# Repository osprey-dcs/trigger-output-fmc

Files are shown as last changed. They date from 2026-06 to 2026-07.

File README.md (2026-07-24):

# Trigger Output FMC

A single width HPC FMC board which provides 16 low jitter TTL outputs,
along with two Si5394 jitter cleaners with outputs connected to the MGTREF capable
when matched with the [LBL Marble](https://github.com/BerkeleyLab/Marble) FMC carrier.

This design is Open Hardware created by Osprey DCS and published under the terms of the
[CERN Open Hardware Licence Version 2 - Strongly Reciprocal](cern_ohl_s_v2.txt) license.

This repository contains KiCad 9.0.4 design files.

- [Data sheet](datasheet.md)
- [Current generated](https://osprey-dcs.github.io/trigger-output-fmc/)
  - [Schematic](https://osprey-dcs.github.io/trigger-output-fmc/trigger-output-fmc-schematic.pdf)
  - [BoM](https://osprey-dcs.github.io/trigger-output-fmc/trigger-output-fmc-bom.csv)
  - [STeP model](https://osprey-dcs.github.io/trigger-output-fmc/3D/trigger-output-fmc-3D.step)

## Block Diagram

Block diagra

## Status

Incomplete, under development, and not yet produced.

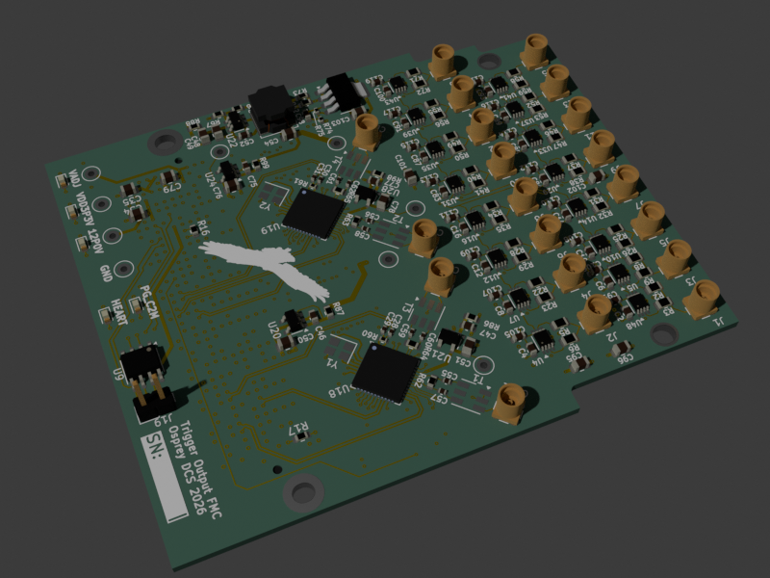
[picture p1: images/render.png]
Preview Render


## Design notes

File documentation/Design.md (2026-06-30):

# Osprey EVR FMC Design Goals

## High level specifications
### Jitter Cleaner
- 2+ LVDS outputs
- Controlled by 2.5V logic from the FPGA (to avoid level shifting)
- Frequencies of interest are 100MHz-250MHz

### Digital I/O
- 16+ outputs with a couple of inputs
- Some/all outputs can drive 50ohm
- Better than 20ps of jitter on clocked digital outputs

# Osprey EVR FMC Part Selection

## Clock Jitter Cleaner Selection

### Skyworks Parts
#### Si5315/16/17/19 - 300pS jitter
- These parts are quite simple and similar
- 3rd Gen DSPLL
- They have a PPL Bypass mode which could be nice for testing.
- CON - these parts seem optimized to operate at fixed tables of frequencies, but will work at 125MHz
Out of this bunch the Si5317A/B seems like it best matches our needs. has 125MHz +/-5MHz options.
These are available form Mouser and Digikey for $15-$20

#### Si5342-45 - 90pS jitter
- 4th Gen DSPLL
- Recommended DSPLLs for Line Card by Skyworks: [link](https://www.skyworksinc.com/-/media/Skyworks/SL/documents/public/application-notes/an1077-selecting-clocks-for-timing-synchronization.pdf)
 - Con - may need level shifting for SPI bus
Out of this bunch the Si5342B seems like it best matches our needs.
These are available form Mouser and Digikey for $26
#### Si5392-95 - 75pS jitter
- This part was used by Paul B. in another similar role but is a clock gen
- 4th Gen DSPLL
- A slightly updated Si534* part with similar combabilities (Drop-in compatible) but options for integrated XTAL
Either Si5392 or Si5394 with a A or B speed grade
These are available form Mouser and Digikey for $35-40
### TI Parts
#### LMK04100 family ~ 200pS jitter [datasheet](https://www.ti.com/lit/ds/symlink/lmk04111.pdf?ts=1769610888824)
- Simple, cheap ($<10), not readily in stock
- require external loop filter (a bit harder to design board for)
- LMK04131
#### LMK04000 family ~ 150pS jitter [datasheet](https://www.ti.com/lit/ds/symlink/lmk04033.pdf?ts=1769572954419)
- require external loop filter (a bit harder to design board for)
- LMK04033 seems like an ok part
### Analog Parts
 - Parts with dedicated jitter cleaning available are quite complicated, and try to integrate more than just jitter cleaning.

## Directly Clocked outputs
There was an idea to clock the Digital I/O directly from the jitter cleaner rather than feeding it back to the FPGA.

- Thinking through this option controlling phase of the clock (from IC) and data (from FPGA) may be an issue.
		- Not sure if this an issue as it could be calibrated out in a consistent way
		- It may be harder to sync outputs from 2 nodes

## SI5392 Setup
- [datasheet](https://www.skyworksinc.com/-/media/Skyworks/SL/documents/public/data-sheets/si5395-94-92-a-datasheet.pdf)
- [Si5395/94/92 Any-Frequency, Any-Output, Jitter-Attenuators/Clock Multipliers Family Reference Manual](https://www.skyworksinc.com/-/media/Skyworks/SL/documents/public/reference-manuals/si5395-94-92-family.pdf)
- [Recommended Crystal, XO, TCXO, and OCXO Reference Manual for High-Performance Jitter Attenuators and Clock Generators](https://www.skyworksinc.com/-/media/Skyworks/SL/documents/public/reference-manuals/si534x-8x-9x-recommended-crystals-rm.pdf)

### Choosing a XTAL
- Looked at high initial tolerance (10ppm or below) parts at 48MHZ from the chart
- Selected Kyocera CX3225SB48000D0F PJC1 based on availability

### Power Supplies
- section 14 in reference manual mentions a few things
	- It is recommended to use a 1 μF 0402 ceramic capacitor on each VDD for optimal performance. It is also suggested to include an optional, single 0603 (resistor/ferrite) bead in series with each supply to enable additional filtering if needed

	- Four classes of supply voltages exist on the Si5395/94/92:
		- VDD = 1.8 V (Core digital supply)
		- VDDA = 3.3 V (Analog supply)
		- VDDOx = 1.8/2.5/3.3 V ± 5% (Clock output supply)
		- VDDS = 1.8/3.3 V ± 5% (Digital I/O supply)
	- I will level shifter for VDDS based IO to FPGA?

- M2C avoid becuase it goes through mux
- check for CM requirments of output of chip to input of fpga line (both GBT and CC)
	- .3 - 1.5V CM

A clean 3.3V is preferred (for the analog core) over the 3.3V from Marble

1st approach is 12V -> ~4.5V ->(LDO) 3.3V

Switcher
both are some of the most available part/ are simple/ and will work
Diodes Inc - AP62200TWU-7
TI - TPS56x200

LDO to 3.3V

# Digital Outputs
## Goals 
- Low Output Jitter
	- 20pSec 
- 50ohm drive capable LVTTL?

## Comparable
MRF EVR
	- 4x "programmable front panel TTL outputs"
	- 3x "differential CML pattern outputs capable of RF recovery"
	- jitter typically < 15 ps rms for TTL outputs, < 5 ps rms for CML outputs
Universal IO
	 - LVTTL Output
		 - Seem to use RF amp
	 - LVTTL Output with delay tuning
		 - Seems to use some LVDS/LVPECL/CML delay IC ex:NB6L295
			 - fine tunes pulse in 10s pico-sec increments

## Our Outputs
Currently using FPGA GPIO / LVCMOS
 - Kintex7 switching datasheet [link](https://docs.amd.com/v/u/en-US/ds182_Kintex_7_Data_Sheet)
	 - Table 20?
- Use weak-drive LVCMOS outputs to appox 50ohm drive pg. 46 [UG483](https://docs.amd.com/v/u/en-US/ug483_7Series_PCB)
- potential issues/sources of jitter with SE
	- FPGA supply noise coupling into GPIO threshold
	- Receiver threshold noise
	- Ground bounce on single-ended outputs (*more a problem with clocks than our pulses)
- Using LVDS/diff outputs should improver these at the cost of complexity

## Signal Path options
signal
### Diff Receivers
https://www.ti.com/product/DS90LV028A0 
DS90LV048 - quad

### Op-amp to drive 50ohm
ADA4311
AD8009
### Comparators - excellent jitter but for CML output
https://www.analog.com/media/en/technical-documentation/data-sheets/ADCMP604_605.pdf
TLV3601
LMH7220
LTC6752
ADCMP580

### LVDS Buffer/Dist IC's to move to a front panel
https://www.ti.com/product/DS90LV004
https://www.ti.com/product/DS25BR440
https://www.ti.com/product/DS15BR401
https://www.ti.com/product/DS15BR400
https://www.ti.com/product/DS10BR254
https://www.ti.com/product/SCAN90004

## Powering Digital Outputs
Have a separate switched rail to power this
- 1 output needs 99.4mA if shorted; 49.8mA under normal conditions
- Split power into 2x 8Ch sections
- Possibly isolate the comparators too.

Low dropout LDO options
- qualities
	- 1A output
	- fixed (ideal)
	- low dropout of less than 500mV
	- Available on Digikey/Mouser 
-Looked at
- TPS737
- TPS7A91
- TPS7A94
- TPS7A80
- TPS759P
- TLV796
- TLV759

# Board Stackup
Board stackup and Impedance

F - CLK
1 - GND
2 - LVDS
3 - GND
4 - PWR
5 - MISC& Power Previously 2 and 4
6 - GND
B -MISC

External Layers
	- .21mm Trace/.2 Width
		- Gives 106 on Kicad with Zeven 68
		- Gives 94 on Saturn with Zeven 63; Zo 54
Interal Layers
- .15mm Trace/.25 Width
	- - Gives 94.5 on Saturn with Zeven 54; Zo 50.5

Old Layer stackup - For note
1 - Z0
2 -GND
3 - in2  -pwr
4 -in3 -lowspeed
5 -GND
6 - Z0

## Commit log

2026-03-14 Start of project
    - Based on FMC Template
    - Layout needs to be finished
    - Some Schematic cleanup is needed
    - All BOM/manufacture data needs to be looked over
    [Digital_IO.kicad_sch, Jitter_Cleaner.kicad_sch, Level_Shift.kicad_sch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]
2026-03-17 Completed Schematic
    Completed Schematic Draft
    - Includes careful pin mapping to avoid conflicts with other firmwares
    - Roughed out LCB layout high speed traces, and FMC breakouts.
    Layout and BOM are still WIP
    [Jitter_Cleaner.kicad_sch, Power.kicad_sch, evr-fmc.kicad_pcb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]
2026-03-26 Updated Schematic and continued layout work
    schematic:
    - Added 0ohm resistor in power section
    - Added pull up and down to digital lines to define powerup behavior
    - Added some power filter between jitter cleaner IC's
    layout:
    -Overall Still WIP
    -defined all needed fmc pins
    -started layout of critical clock signals and connector locations.
    [Jitter_Cleaner.kicad_sch, Power.kicad_sch, evr-fmc.kicad_pcb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]
2026-04-02 Revised Si5394 part and schematic changes
    - Revised Si5394 part
    - Changed OE pin connection on Si5394
    - Removed OE from SPI group
    [Jitter_Cleaner.kicad_sch, Power.kicad_sch, eeprom.kicad_sch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]
2026-04-07 Updated Cleaner Control Signaling
    [Jitter_Cleaner.kicad_sch]
2026-04-09 Schematic Updates
    -Added Heartbeat LED
    -Assigned Jitter cleaner OE to FPGA pins
    -Changed LDO parts
    [Jitter_Cleaner.kicad_sch, Power.kicad_sch, evr-fmc.kicad_pcb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]
2026-04-16 Finalized Schematic and Updated Layout
    [Jitter_Cleaner.kicad_sch, Power.kicad_sch, evr-fmc.kicad_pcb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]
2026-04-28 Updated Layout
    - parts floor planed
    - need to finish digital IO routing
    [evr-fmc.kicad_pcb]
2026-04-30 Layout draft nearly complete
    - Changed some digital IO pinout on the FMC
    - Most areas routed
    [evr-fmc.kicad_pcb, fmc.kicad_sch]
2026-05-05 Draft Layout Complete
    -Draft Layout Complete
    - Silkscreen need to be complete
    - some Digital IO swapped FMC pins
    [Jitter_Cleaner.kicad_sch, Power.kicad_sch, evr-fmc.kicad_pcb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]
2026-05-07 Final Draft - Ready to Review
    Things to do:
    Round diff traces before generting fabrication files
    Change name of project to 'trigger output fmc'
    Align this with recent updates to fmc-template
    Updates:
    - Cleaned up BOM
    - Arranged silkscreen and fab layers
    - Shortened power traces from LDOs to Jitter Cleaner IC
    - Fixed traces/planes with sharp corners
    - Straightened out all MMCX Test Ports
    [Jitter_Cleaner.kicad_sch, Power.kicad_sch, eeprom.kicad_sch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]
2026-05-07 Final Draft - Ready for review
    - Changed area behind FMC connector to match the new Osprey FMC template
    - This includes a new 12V LED, more robust power input traces, arranged elements for readability.
    Round diff traces before generating fabrication files
    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
    [Digital_IO.kicad_sch, Jitter_Cleaner.kicad_sch, Power.kicad_sch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]
2026-06-23 Changed Trigger Outputs Topology
    - Changed to a comp to digital TX design
    - Added power section to support this change
    [Digital_IO.kicad_sch, Jitter_Cleaner.kicad_sch, Power.kicad_sch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]
2026-06-24 Updated Layout - roughly floor planed all parts on board
    - All parts fit on the board but routing may still result in power sections moving
    [Digital_IO.kicad_sch, diff_comp_out_buffer.kicad_sch, evr-fmc.kicad_pcb]
2026-06-30 Added Level Shifter schematic & moved symbols
    - Created a separate Level Shifter schematic to prepare use of some gates for Digital output enables.
    [Digital_IO.kicad_sch, Jitter_Cleaner.kicad_sch, Level_Shift.kicad_sch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]
2026-06-30 fix case of Level_Shifter sheet name
    [evr-fmc.kicad_sch]
2026-07-02 Routed LVDS lines
    - Routed LVDS lines
    - Swapped some digital output pairs
    - Properly connected the output enable signal for digital outputs in the schematic
    [Digital_IO.kicad_sch, Level_Shift.kicad_sch, evr-fmc.kicad_sch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]
2026-07-03 Finished Draft Layout
    - Finished Draft Layout
    - Changed Switcher IC
    - Added extra decoupling caps for digital output spikes
    [Digital_IO.kicad_sch, Jitter_Cleaner.kicad_sch, Power.kicad_sch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]
2026-07-07 Fixed Silkscreen and BOM
    All DRC/ERC errors are resolved.
    [Digital_IO.kicad_sch, Jitter_Cleaner.kicad_sch, Level_Shift.kicad_sch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]
2026-07-08 Renamed Project to trigger-output-fmc
    -Renamed project files
    -Removed outdated/unused schematic pages
    [diff_comp_opamp_buffer.kicad_sch, out_buffer.kicad_sch, trigger-output-fmc.kicad_sch]
2026-07-08 Changed mechanical holes to universal Mable footprints
    [Digital_IO.kicad_sch, fmc.kicad_sch, trigger-output-fmc.kicad_sch]
2026-07-10 Final Draft for project
    - Changed LDO for Digital Output driver to a LP3855-ADJ
    - Aligned Digital Output driver sections
    - Added Additional Capacitance on each digital output drive channel
    - Revised Differential Lines geometry on top layer
    - Revised Power routing and internal planes
    [Digital_IO.kicad_sch, Jitter_Cleaner.kicad_sch, Level_Shift.kicad_sch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]
2026-07-15 Fix L1
    Correct Value to match MPN.
    SRN6045TA-3R3Y (ending with 'Y') is the actual part number .
    Add datasheet link.
    [Power.kicad_sch]
2026-07-16 Schematic and Layout Tweaks
    - Updated all vias to 0.6/0.3mm
    - New mechanical universal Marble holes for H2
    - widen the power traces to Test points
    - Add pin 4 of U20/U24 to GND net
    - add a GND pour around U44 for heat
    - Widen GND traces on LDOs (U24/U20)
    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
    [Digital_IO.kicad_sch, Jitter_Cleaner.kicad_sch, Level_Shift.kicad_sch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]
2026-07-17 Updated Layout of XOs and Digital Output Sections
    - Added some additional comments to schematics (Y1&Y2)
    - Added additional ground vias around U44
    - Add GND planes around 1.8V LDOs (U21&U28)
    - Straightened out some power routing tracks with 90deg bends
    - Revised routing of Y1&Y2
    - Revised routing of each digital output section
    - All DCR/ERC errors resolved.
    [Digital_IO.kicad_sch, Jitter_Cleaner.kicad_sch, Level_Shift.kicad_sch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]
2026-07-23 Updates after external review
    - Changed Value of R66 & R67
    - Added 100nF cap (C104) at input of U22
    - Added GND via in center of U24 (like other LDO's)
    - Changed 1nF Caps in Digital output section to 10nF
    - Rounded pads of (T1-T4)
    - Adjusted traces between T1-T4 and their respective MMCX connector
    - Added FB1 & C136 at output of U22(5.45V switcher)
    - Exchanged R88(0ohm) for a Ferrite Bead at input to U22(5.45V switcher)
    - Revised layout of U22 area to more closely follow the data sheet.
    - Exchanged R73&R42 at input to U44 for a ferrite bead (FB3)
    - Exchanged R86/87/98/99 at input of TLV757 LDO for ferrite beads
    - Added 1uF caps to VDD, VDDA, and VDDS power rails on Jitter Cleaner
    - Changed C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
    [Digital_IO.kicad_sch, Jitter_Cleaner.kicad_sch, Power.kicad_sch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]
2026-07-24 Updates after external review
    - Removed various construction lines on comments layer
    - Corrected various 50ohm SE traces on external layers to 0.26mm width
    - Shortened up longer traces where possible on external layers and LVDS (in5)
    - Made routing of CLK signals to MMCX test ports consistant
    - MAJOR UPDATE to XTAL (Y1&Y2)
    This now follows the family reference manual to properly isolate the XTAL
    This then required the following changes:
    - Swapped layer In2 with In5 (to keep LVDS between GND layers)
    - Swapped layer In3 with In4 (to keep LVDS between GND layers)
    - Revised gate mapping of level shifted signals on the IC (no FMC pinout change)
    - Significant revision to routing around these are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
    [Digital_IO.kicad_sch, Jitter_Cleaner.kicad_sch, Level_Shift.kicad_sch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]
2026-07-24 Small Tweaks
    - Updated readme with kicad version
    - fixed break in ground plane near Y2
    - added exclusions with written exceptions for 4 DRC errors (where we grounded level shifter gates)
    - Fixed whitespace at the end of MPNs
    [Digital_IO.kicad_sch, Jitter_Cleaner.kicad_sch]
2026-07-24 Changed LDO gnd pours
    -LDO ground pours had odd gerber outputs with thermal spokes.
    These are now solid pours.
    - Added small note on 100ohm termination
    [Jitter_Cleaner.kicad_sch]
2026-07-24 project evr-fmc -> trigger-output-fmc
    [Digital_IO.kicad_sch, Jitter_Cleaner.kicad_sch, Level_Shift.kicad_sch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]
2026-07-24 Added Version to Silkscreen
    Added Version to Silkscreen
2026-08-21 Custom DRC for long differential pairs
    Add netclass "LongDiff".
    [diff_comp_out_buffer.kicad_sch, fmc.kicad_sch]
2026-09-29 Revision based on pre-production
    -Added pull-down on the OE for the Digital output buffers
    - increase board edge (was 0.3mm, but via and traces are 0.5mm away now)
    - move power vias away from board edge
    - Increase power via size from 0.6mm/0.3mm to 0.8mm/0.4mm in a couple of places
    - Naming of level shifter output enable changed to make function clear throughout the design.
    - Revised SMPS layout slightly to better use the space.
    [Level_Shift.kicad_sch, fmc.kicad_sch, trigger-output-fmc.kicad_pcb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]
2026-10-01 Updates from Pre-production boards
    - removed ground from mounting holes and added no-pop 0805 resistors to optionally ground the mounting holes.
    - Adjusted placement of some test points.
    - Made the test point loops non-populated parts, the pads will remain.
    - Added silkscreen labels to the test points.
    - Fixed pulldown resistor added in prevoius commit.
    [Jitter_Cleaner.kicad_sch, Level_Shift.kicad_sch, Power.kicad_sch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]
2026-10-06 Updated Version Number to 1.1
    Updated Version Number to 1.1
    -Added Test point for digital output LDO supply (TP10)
    [Digital_IO.kicad_sch, Jitter_Cleaner.kicad_sch, Level_Shift.kicad_sch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]
2026-10-09 Minor Silkscreen fix
    Fixed minor silkscreen overlap
    [trigger-output-fmc.kicad_pcb]
2026-10-09 Added 50mA load with LED
    [Power.kicad_sch, trigger-output-fmc.kicad_pcb]
2026-10-09 Changed Load Resistors and LED to DNP
    [Power.kicad_sch, trigger-output-fmc.kicad_pcb]
2026-11-12 new datasheet for jitter cleaner crystal
